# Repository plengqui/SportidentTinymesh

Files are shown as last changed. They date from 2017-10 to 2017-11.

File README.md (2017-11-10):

# Sportident online control using Tinymesh 169Mhz radio
A forest-optimized, reliable mesh radio for Sportident with up to 1,5km per hop.
This document introduces the project idea and product vision on a high level.
# Project context and background
In orienteering and other outdoor sports, the [Sportident](https://www.sportident.com/) system is often used to electronically register when a participant passes a checkpoint. One drawback of Sportident is that the checkpoint pass time registrations cannot be read out until the participant has finished the course. In order to make sports using the Sportident system more exciting for the audience, there is a need for real-time communication from the checkpoints to the competition administration at the arena. A number of solutions already exist for this, such as the excellent [Radio Online Control](http://olresultat.se/), current loop signaling over military [telephone wire](http://hem.bredband.net/sunjo/index.htm), [jSh Radio](http://radio.jsh.de/), etc. While they each have their advantages, most solutions are a bit bulky which makes it burdensome to deploy more than a couple of online checkpoints in each race. For solutions that rely on mobile data networks, there is also the risk at big competitions that the network becomes overloaded on competition day by the large number of runners and viewers appearing on the arena, which is typically a location where mobile networks are not dimensioned for such high load. 
# Product vision
This project aims to produce a neat lightweight radio solution that is easy to deploy in forest conditions, while being very reliable in terms of delivering 100% of punches to the arena in all possible weather conditions. The finished product is a radio unit - a small box about the size of a fist - which is directly attached to a flexible 130 cm roll-up antenna. The antenna + radio unit can hang from a tree anywhere within 8m from the Sportident units at the control. No cabling is needed on the ground. No calibration of directional antennas is needed.
About 10 radio units including antennas can be carried in a backpack and easily deployed by one person with very limited technical knowledge. 
# Technologies used
## Tinymesh
The radio units communicate using a widely used and well supported mesh radio protocol from Radiocrafts called Tinymesh. They use the 169 MHz band, which implies wavelengths of almost 2 meters. Thus they have very good propagation even through dense and wet forest. Distances of 1,5 km per hop have been tested with continuous operation through hilly forest with 500mW effect and Slim Jim antennas. Tinymesh is a self-configuring, self-healing, monitorable mesh technology, implemented in a small surface-mounted component containing both transceiver and protocol logic.
Nodes in a Tinymesh network can be of two types: Router or Gateway. There is only one Gateway per network. All serial data sent from Rounters are automatically routed to the Gateway.
The [Tinymesh datasheet](docs/RCxxxxHP-TM_Data_Sheet.pdf) from Radiocrafts contains everything we need to know in this project, from an overview of the solution to detailed explanation of the protocol and packet formats. I have highlighted the parts of the datasheet that are relevant to this project and added some annotations. The specific module we use is RC1701(HP)-TM, whose default operating frequency is 169.40625 MHz with max effect of 500mW.
This radio band is unlicensed in most european countries, including [Sweden](https://www.pts.se/sv/Bransch/Radio/Radiotillstand/Undantag-fran-tillstandsplikt/):
>88 § 169,400–169,475 MHz: Radiosändare för ospecificerat tillämpningsområde. Högsta effekt: 500 mW e.r.p. Kanaldelning: Upp till 50 kHz. Sändningscykel: < 1 %

>89 § 169,400–169,475 MHz: Radiosändare för mätutrustning. Högsta effekt: 500 mW e.r.p. Kanaldelning: Upp till 50 kHz. Sändningscykel: < 10 %.

## Slim Jim antenna
slimjim1 slimjim2

The Slim Jim antenna is perfect for this application, being easy to transport rolled up, and quick to deploy by just hanging it from a tree nearby, up to 8m from the Sportident station. The antenna is 130 cm long, and the small Radio Unit box can be attached diretly at the lower end of the antenna. 

## Sportident Short Range Radio (SRR)
The Sportident units at the control are [SRR](https://www.sportident.com/images/PDF/1_si_base_products/8_si-radio/SRR-Kit/SPORTident_SRR_en.pdf) stations, which communicate with the radio unit via a proprietary Sportident radio protocol on the 2,4 GHz band. 

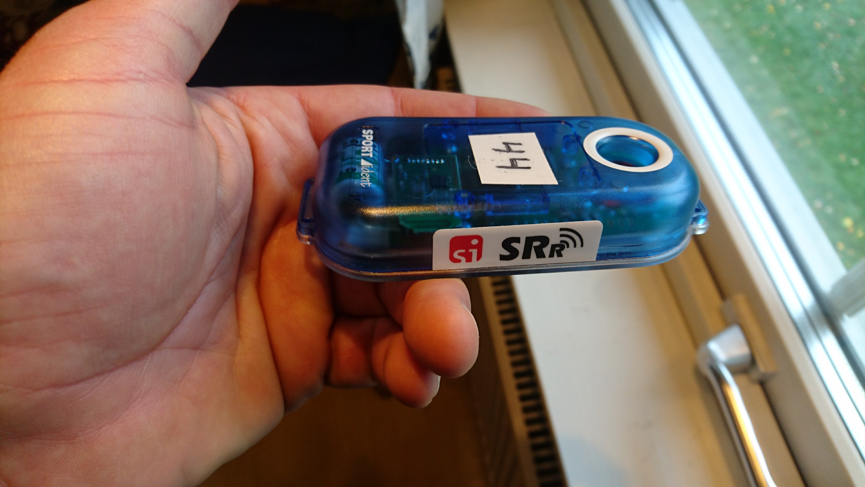
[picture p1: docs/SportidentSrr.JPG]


# System design and architecture
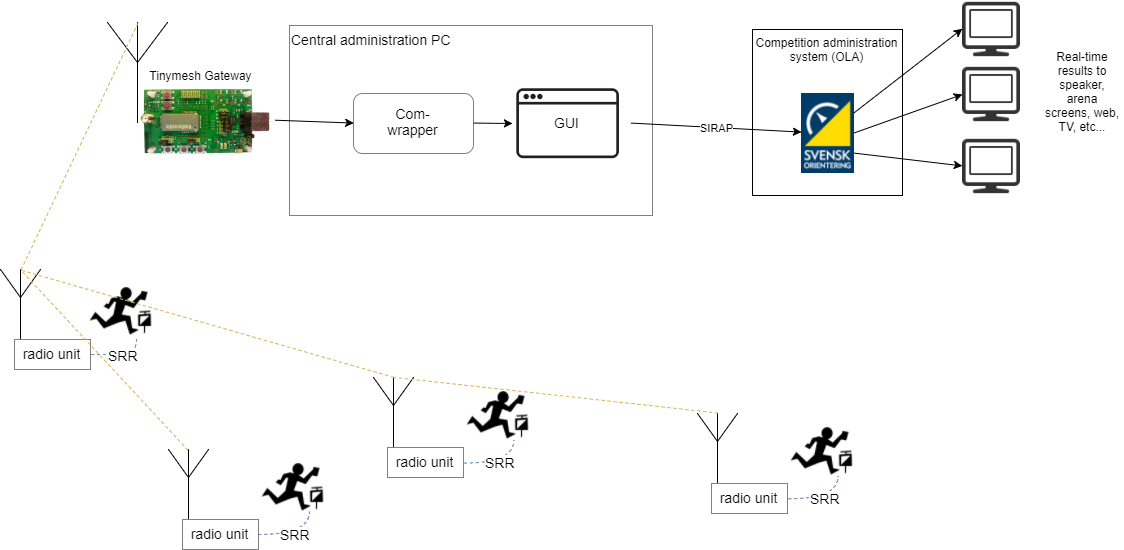
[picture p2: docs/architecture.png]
architecture

Apart from the standard off-the-shelf Sportident SRR stations, the system consists of two main parts:
1. The neat field-deployable radio unit, of which there will be one per checkpoint. The radio unit receives punch data from the Sportident stations over SRR, and retransmits it over the 169 MHz Tinymesh network. The Tinymesh network architecture has one central Gateway node to which all data is sent.
2. The Gateway, consisting of a Tinymesh radio module directly connected to a PC running our custom python Gateway Application which parses the Tinymesh packets and forwards the Sportident punch data to the competition administration system. Integrates with competition administration system like OLA or MeOS using the SIRAP protocol.
There is pretty comprehensive documentation of the Gateway Application code available in its [README](https://github.com/plengqui/GatewayApplication/blob/master/README.md).

## The radio unit

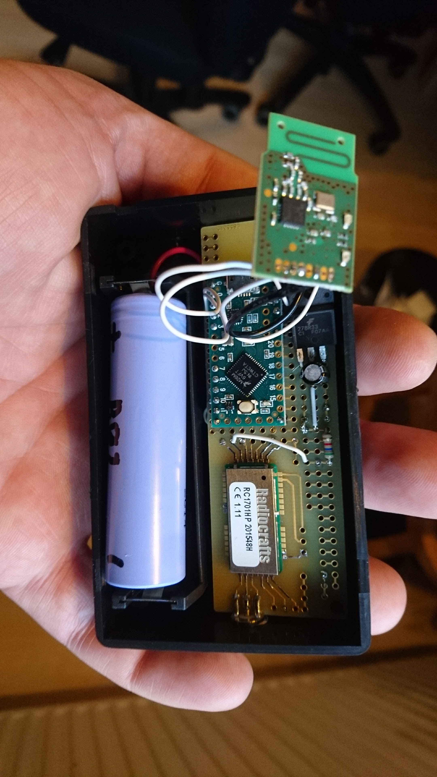
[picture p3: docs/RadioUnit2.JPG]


The radio unit is a small box of electronics with only one external connector for the SlimJim roll-up antenna. As mentioned, the antenna and the radio unit box are meant to hang from a tree nearby the checkpoint. Inside the box, there is a custom made printed
circuit board (PCB) with:
- a Sportident SRR receiver chip, which listens to 2,4GHz for punch packets and sends them out over UART serial. 
- A Teensy-LC (a cheap small Arduino style microcontroller) receives the punch data, creates a Tinymesh data packet and passes it on to the Tinymesh radio module, again over UART serial. 
- The Tinymesh radio module sends the data packet with the punch data out on the Tinymesh network which forwards it to the gateway Tinymesh module. The model number of Tinymesh used is RC1701(HP)-TM.
- The Teensy-LC microcontroller also buffers punches if the Tinymesh module should be busy or waiting for a free timeslot on the frequency. It also sends monitoring packets every 10 seconds so that the central pc application can allways know all radio units are up and connected.
- Battery: 18650 Lithium cells and a voltage regulator, serving the 3,3V needed by Tinymesh and Teensy-LC.
- Antenna for 169MHz with SMA male connector. Either a SlimJim, which you can [build](https://www.essexham.co.uk/slim-jim) or [buy](http://www.2wayelectronix.com/). Or a "normal" whip antenna like [this one](https://www.digikey.se/product-detail/en/taoglas-limited/FW.80.SMA.M/931-1195-ND/3664652). SlimJim is best for real-world application in the woods. A whip is good for lab and test.

## The Gateway
This is the central part of the system that collects all punches from all controls and forwards them to the competition administration system. It also monitors the health and connectivity status of all controls. The Gateway is a Tinymesh module configured as the gateway of the mesh network, connected with simple serial to a PC running the Gateway Application. 
To save time, I have so far used the Tinymesh Demo Kit (RC1701HP-TM-DK) which has a USB connection and appears as a logical COM port in the PC. However, it should be quite easy to use a Radio Unit as gateway (see TODOs below).

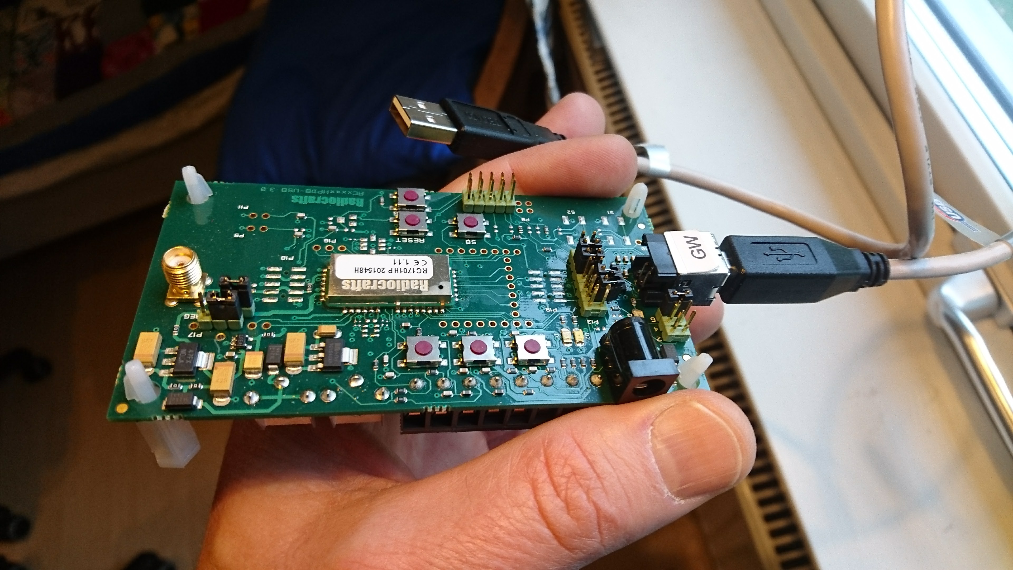
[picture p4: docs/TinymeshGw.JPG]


The Gateway Application is written in Python 3 and consists of two parts: a small simple script running as a separate process which just listens to the COM port of the Tinymesh gateway and writes every received packet to a store-and-forward queue. This queue is read by the main python application which parses each Tinymesh packet on the queue and handles it. Packets that are punch registrations are sent to the competition administration system using the SIRAP protocol. The application also has a GUI that shows status and health of each control, and any alarms:

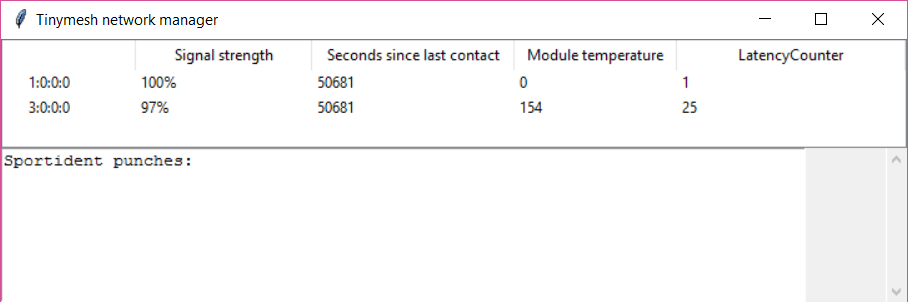
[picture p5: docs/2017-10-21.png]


The Github repository for the gateway application is [here](https://github.com/plengqui/GatewayApplication/).

# Project progress and status

This has been completed so far:
1.	Selected and tested radio, frequency and antenna solution. 1,5km hop reached with rollup slim-jim antenna using the Tinymesh RC1701(HP)-TM with 500 mW effect on the license free 169 MHz ISM band. 
2.	Verified Tinymesh mesh radio network in real Orienteering competition using Tinymesh developer kits in July 2016. Two controls and one gateway.  This worked great. All punches were received online. 
3.	Written pc application in python to receive and parse Tinymesh and Sportident packets. Use Tinymesh in packet mode, to monitor the health of the mesh network using the packet metadata and the various command packets of Tinymesh. This is referred to as the Gateway Application above. 
4.	Designed and built a neat field-deployable Radio Unit with custom made printed circuit board (PCB), surface-mounted Tinymesh chip, battery, and a Teensy (a cheap small Arduino style microcontroller) for control logic.
5.	Written and tested Teensy code to simulate Sportident punches and send them to the Tinymesh radio module. Tested connectivity from the Teensy to the python application running on the PC, over Tinymesh radio. Load tested with 3 simulated punches per second, continuously for 2 hours.
6.  Got the Sportident SRR chip working with the Radio Unit. So now full integration from Sportident punch to Gateway Application is done. Rudimentary support for flow control reading the Tinymesh CTS status before and after sending each packet. So far relies on Teensys serial buffers for buffering.
7. Implemented SIRAP protocol in the Python Gateway application. Tested with OLA competition administration system. Now we have a complete end-to-end system!

# Getting Started
List of needed components for the Radio Unit, how to get them and putting it all together is [here](./RadioUnit/README.md).

When the Radio Unit is built, you just need to:
1. connect the antenna
2. upload the sketch teensy-sportident-srr.ino to the Teensy using the [Arduino IDE](https://www.arduino.cc/en/Main/Software)
3. connect a usb power source to the micro usb of the Teensy.
4. attach the gateway demokit module to the pc.
5. start the [Gateway Application](https://github.com/plengqui/GatewayApplication/blob/master/README.md) on the PC 
6. try some punches in the SRR station!

Any problems? Just drop me an email at ```per (kanelbulle) lengquist.se```

# TODO: ideas for further improvement
-	Build more Radio Units and test in more real orienteering events. Please drop me an email if you know where to borrow more SRR master stations.
- Implement support for RS232 Sportident stations. Support in Teensy for multiple stations (multiple serial ports in).
- Select a good solution for physical enclosure. Also decide battery solution: powerbank or 18650 LiIon cells. 
- Invent a way for the person deploying the Radio Units in the forest to get verification that each deployed online control works end-to-end. Perhaps by the Gateway Application publishing its status logs on a web page or [Slack](https://api.slack.com/).
- Use a Radio Unit as Gateway instead of the rather expensive Demo Kit: Write a Teensy program to configure the Tinymesh module as a gateway. Then use a [simple Teensy program](https://github.com/arduino/Arduino/blob/master/build/shared/examples/04.Communication/MultiSerial/MultiSerial.ino) to pipe through serial data between USB serial and the Tinymesh in normal operation.

Any suggestions or feedback? Just drop me an email at ```per (kanelbulle) lengquist.se```

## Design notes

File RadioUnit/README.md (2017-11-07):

# Building the Radio Unit
Here is info about getting components and putting it together.

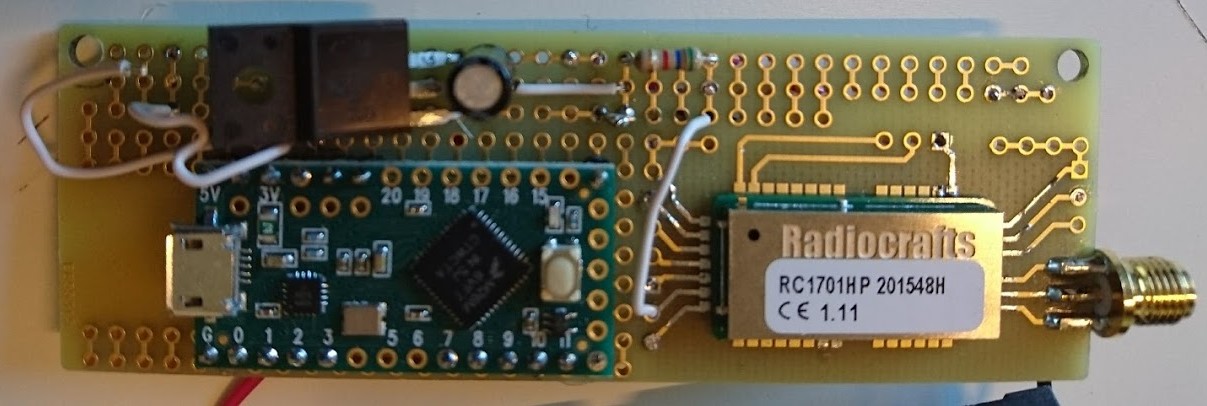
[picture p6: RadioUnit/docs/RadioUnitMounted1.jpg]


## Basic components to get a working unit up for lab/development purposes

### RC1701HP-TM	Tinymesh transciever module


Borrow a couple from me, or buy your own from:
1. http://www.actesolutions.se/sv/produkt/rcxxxx-tm (See how to order from Sweden below.)
2. https://www.digikey.com/product-detail/en/radiocrafts-as/RC1701HP-TM/RC1701HP-TM-ND/7100560 (not possible to ship to sweden)

### PCB with copper pattern for the Tinymesh module footprint
See [PCB Readme](./PCB/README.md) on how to order one.

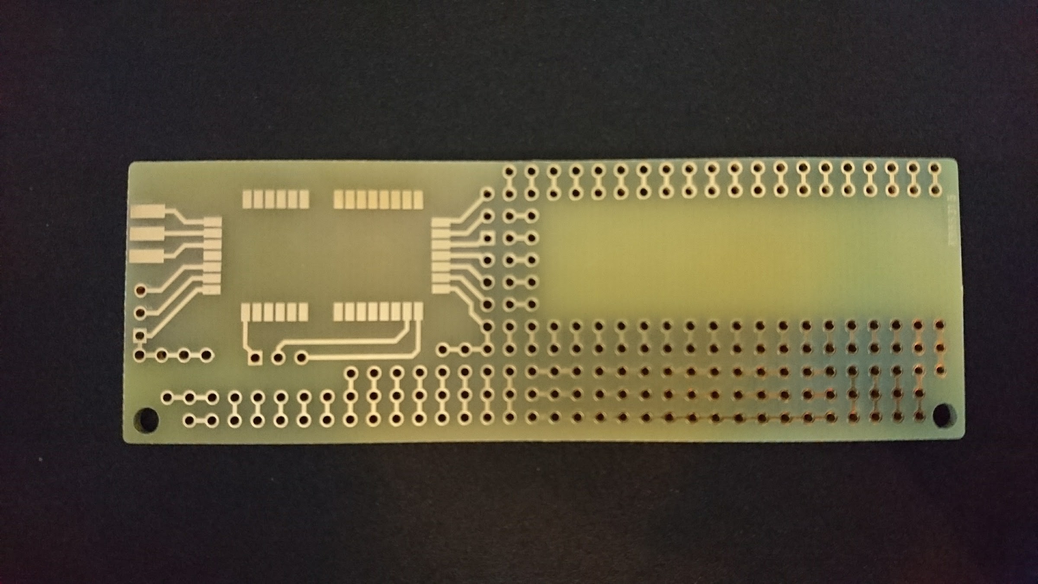
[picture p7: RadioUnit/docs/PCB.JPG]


### SMA female connector for PCB mount
https://www.electrokit.com/sma-hona-pcb-4mm-djup.49423

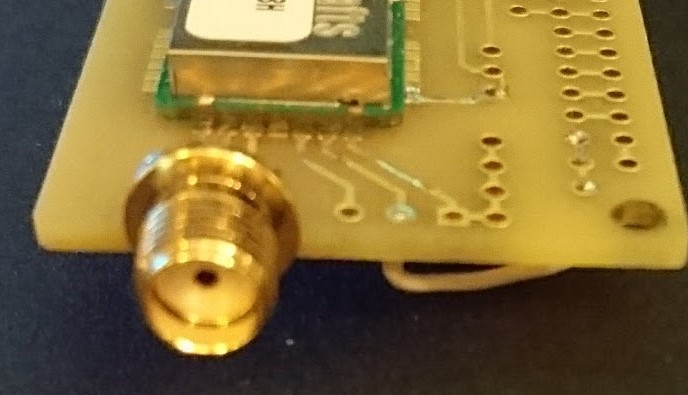
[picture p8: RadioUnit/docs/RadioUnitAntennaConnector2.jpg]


### Whip antenna for 169MHz with SMA male connector 
https://www.digikey.se/product-detail/en/taoglas-limited/FW.80.SMA.M/931-1195-ND/3664652

### Teensy-LC microcontroller
https://www.electrokit.com/teensy-lc.52909

## Connecting to a Sportident station

SRR module for connecting to SRR BSM station: 
http://www.sportident.se/order.aspx?id=472
To get the actual module (a 1x1 inch circuit board with only the SRR radio and UART connectors) you are supposed to *open up* the plastic enclosure of the dongle and *BREAK THE CIRCUIT BOARD IN HALF*! Yes, it sounds crazy but it's true. Look at the picture below and you can see the broken edge to the right. There is a notch on either side of the board where you are supposed to break it. If you want to configure if it should transmit on blue or red SRR channel, you need to do that (with SI-Config+) before you break the board.

Alternative: wired connection to RS232 BSM station
- RS232-to-UART converter
https://www.electrokit.com/en/max3232-breakout.49804
- RS323 connector
https://www.electrokit.com/en/dsub-9-conn-male.42706

## Non-mandatory extras
Teensy 3.2 may be an alternative to the Teensy-LC. The LC is cheaper, but the 3.2 has an internal voltage regulator that can feed more current (250mA) to power the Tinymesh module.
https://www.pjrc.com/teensy/external_power.html

I recommend headers for mounting the Teensy on the PCB when in the lab/design phase.
- https://www.electrokit.com/stiftlist-2-54mm-1x40p-brytbar.43412
- https://www.electrokit.com/hylslist-2-54mm-1x40p-svarvad-brytbar.44672

Some LEDs and resistors to connect to RSSI and CONN indicator outputs.

### Tinymesh Demo Kit:
https://www.digikey.com/product-detail/en/radiocrafts-as/RC1701HP-TM-DK/RC1701HP-TM-DK-ND/7100561 
I used a demo kit RC1701HP-TM-DK for the Gateway, since it is a ready made appliance that you just connect to the PC with USB. A demo kit comes with 3 units and costs about 320 USD. But you could also design and build your own gateway unit using a Teensy (which just passes serial straight through) and a Tinymesh module. 

## For maximum outdoor range
To use full transmit power, an additional voltage regulator from the USB's 5V to the Tinymesh VCC_PA that takes 3.3V. I think a buck (switched step-down) converter is better than a linear since it is more energy efficient. It is a tradeoff between battery size and complexity of design. It needs to be able to output >800mA (gut feeling estimate). Note that you may need capacitors too, check the datasheet.

Slim Jim VHF antenna tuned for 169.4MHz with SMA male connector.
http://www.2wayelectronix.com/N9TAX-Original-VHF-Slim-Jim-antenna-VHF-STD.htm

## Ordering Tinymesh in Sweden

I just sent email to Acte Solutions order@actesolutions.se .
They need you to order via a company or organization (their systems require and organization number). I used the org nr of my orienteering club whch worked fine. I just made sure I got the invoices by email so I could pay them myself.

When I ordered 2016 the prices were:
34,50 USD each for the modules RC1701HP-TM, minimum quantity 10 pcs.
320 USD each for the demokit RC1701HP-TM-DK.
Prices excluding VAD and shipping. Shipping was about 100 SEK for me. Country of origin was Norway (where Radiocrafts are).
Delivery took about 3 weeks.

## Putting it together
Connect the following:

| Tinymesh connector | Teensy pin |
| --- | --- |
| RXD | TX2 (pin 10) |
| CTS | pin 23 |
| GND | GND |
| VCC | 3.3V |

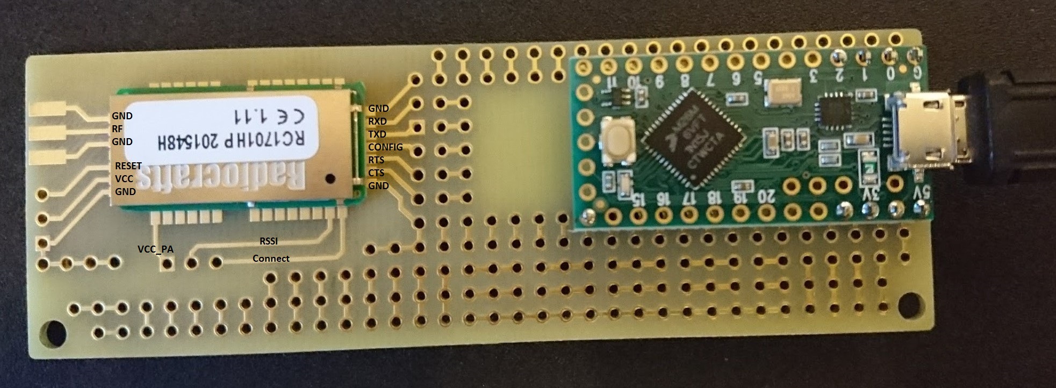
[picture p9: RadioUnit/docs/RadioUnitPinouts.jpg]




Do not connect VCC_PA of the Tinymesh to the Teensy 3.3V, since it can not supply the needed amount of current (~400mA). If you want that extra transmit power, you need to add a step-down converter from 5V to 3.3V. Take the 5V from Vin on the Teensy (which is directly connected to the power wire of the USB contact, and feed the resulting 3.3V to VCC_PA on the Tinymesh.

Solder the SMA connector to the three plates at the edge of the PCB. They are GND, RF and GND. Also solder the SMA connector to the GND plane on the back of the PCB.

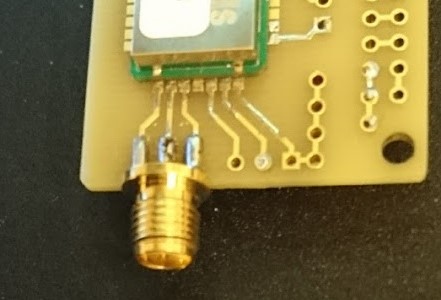
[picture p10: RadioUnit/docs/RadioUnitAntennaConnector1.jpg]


If you use the Sportident SRR module, you connect the following:

| SRR | Teensy pin |
| --- | --- |
| TX | RX1 (pin 0) |
| GND | GND |
| 3 V | 3.3V |

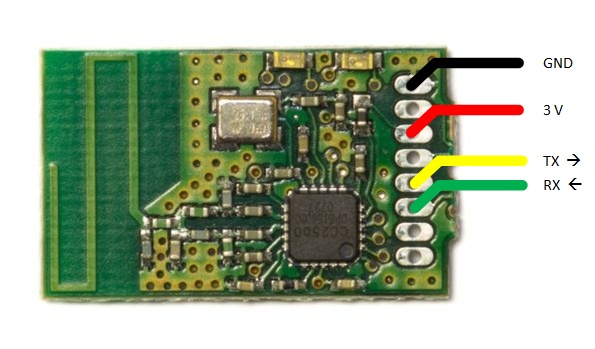
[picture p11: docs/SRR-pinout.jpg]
srr pinout


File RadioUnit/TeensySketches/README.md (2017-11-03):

# Main file
teensy-sportident-srr: The Teensy-LC scetch to use in a Radio Unit. Assumes Sportident SRR connected to RX1.

# Miscellaneous extras
crc-test:	An implementation of Sportident CRC checksum algorithm for Arduino	

punch-simulator:	Makes Teensy simulate Sportident punches and send to Tinymesh.

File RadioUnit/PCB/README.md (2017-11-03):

This directory contains design files for the Printed Circuit Board (PCB) on which the components are soldered. 
The Tinymesh module is surface-mount soldered, while the other components are traditional through-hole. 

The board design has no fixed copper wiring between the components. This makes it possible to use for experimentation and test different designs without printing new PCBs.

The files are created using [Eagle](https://www.autodesk.com/products/eagle/free-download).
I ordered the boards from [Eurocircuits](https://www.eurocircuits.com/blog/NAKED-proto/). 
5 boards cost 48,5 EUR incl VAT and shipping. See order details in the file [E855315.pdf](./E855315.pdf). If you refer to that, or maybe "PCB B0826634", and they have saved my specification and design, you may be able to order new copies the exact same PCB that I got. I can confirm it is suitable for the components I used including the Tinymesh module. 

Here is a good video tutorial (from the great Collin's Lab) on hand solering a surface mount component with QFN package like the Tinymesh module:
https://youtu.be/QzoPxvIM2qE?t=349

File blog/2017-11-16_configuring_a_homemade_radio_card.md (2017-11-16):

# How to configure your radio card with TM-CCT
If you have built a new radio card with a TM and a Teensy, you probably want to configure the TM. At least you need to do that with your gateway since all TM's are factory configured as a router.

Radiocrafts has a real useful and easy to use tool that can be used for configuring the TM. It can also be used for sending test strings between TM's and watching the signal levels. The name of the tool is TM-CCT and it can be downloaded from [here](https://radiocrafts.com/products/tinymesh/#software). Pick the file "[RC Tools - TM](https://radiocrafts.com/uploads/rctools-tm_setup_1_06.exe)" and install it.

For TM-CCT to be able to talk to the TM through the Teensy you need a small sketch that copies everything from the USB-serial to the TM-serial and vice versa. Upload the sketch [tm-config.ino](https://github.com/plengqui/SportidentTinymesh/tree/master/RadioUnit/TeensySketches/tm-config) to the Teensy.

When the sketch is running on the Teensy, start the TM-CCT tool and connect it to the Teensy USB-serial port. Use the default 19200 as baud rate.

Now you are in normal mode (not configuration mode) and when you type something and press enter, it is sent to the TM and you should see the LEDs blinking as the TM transmits what you typed.

To enter configuration mode, click the green and red button on the top left. A dialog saying "Waiting for prompt sign, press CONFIG button!" is shown. While this dialog is showing, shortly connect the CONFIG pin on the TM to GND. (Best is probably to install a push button on the PCB in the final design but for now a jumper wire will do just fine.)

If you suceeded to set the TM in configuration mode both the LEDs should be lit with a steady light and the dialog in TM-CCT should have closed. You can now remove the jumper cable again.

Fetch the current configuration of the TM by clicking the green left arrow. The window to the left should fill up with all current configuration.

Change whatever value that you like, e.g. the Device type on address 0x0E. When finished, click the green right arrow to write the new configuration to the TM.

Go back to the normal terminal mode again by clicking the other button saying "abc123" (or type "X" and Enter). This should turn off the LEDs so they start to blink again and the TM is restarted with the the new config.

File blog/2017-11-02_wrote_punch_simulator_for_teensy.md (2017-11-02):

# Wrote a punch generator for tests
Today I wrote a Teensy program (sketch) to generate synthetic Sportident punches for test purposes.
It went well. The sketch is checked in to [the github repository](https://github.com/plengqui/SportidentTinymesh/tree/master/RadioUnit/TeensySketches/punch-simulator).
The trickiest part was writing the CRC calculating function. I only found a java implementation, which i transcribed to C. 
Each iteration the sketch increments: SI card number by one, punch time by 256 seconds, and memory pointer by 8.
I let it churn out 2-3 punches per second and actually found a timing error in the comwrapper.py script which I fixed. After that it chugged along happily for hours :-)

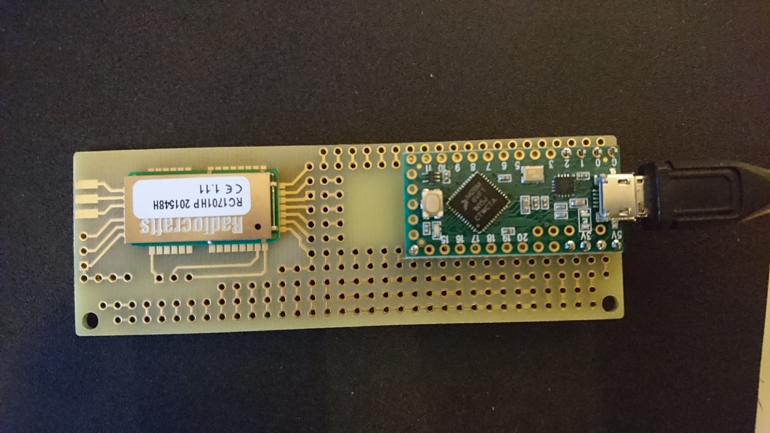
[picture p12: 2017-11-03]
RadioUnit/docs/RadioUnit1.JPG

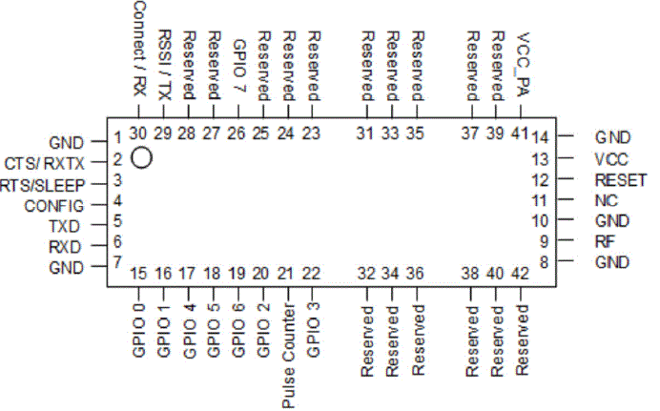
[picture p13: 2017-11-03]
docs/TM.GIF

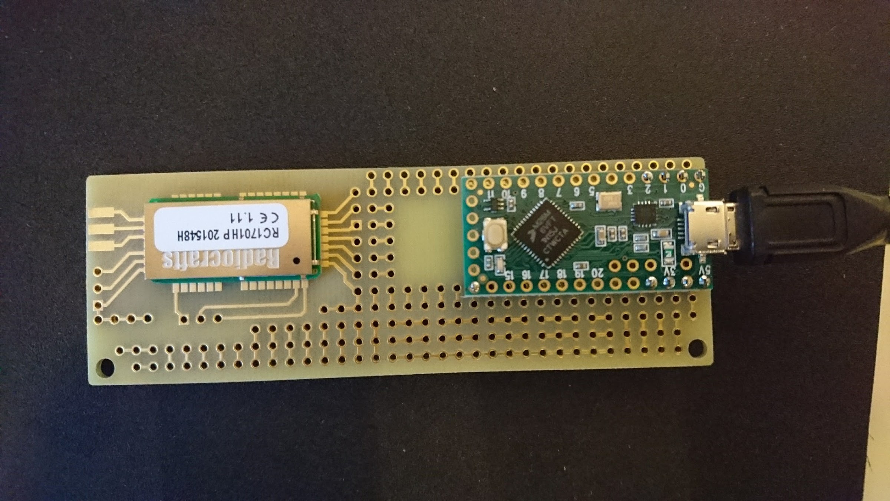
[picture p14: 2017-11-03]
RadioUnit/docs/RadioUnit2.JPG

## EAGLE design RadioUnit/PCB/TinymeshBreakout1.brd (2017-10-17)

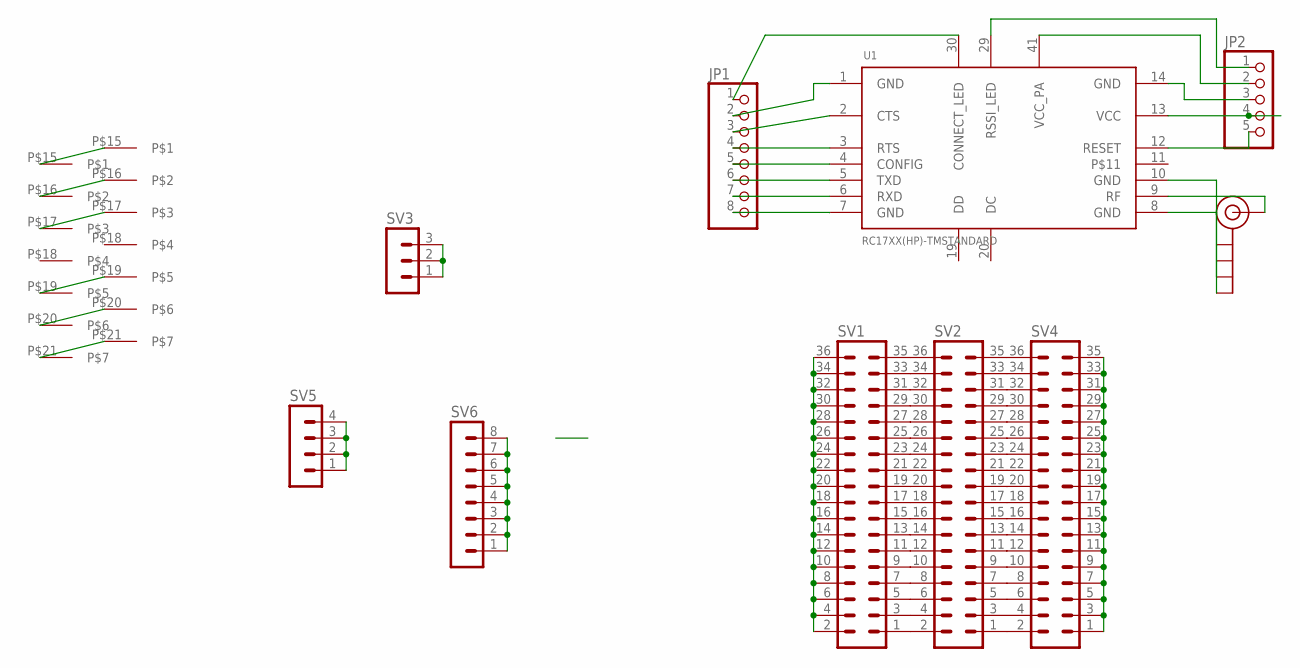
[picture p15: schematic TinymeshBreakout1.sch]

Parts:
J$1: SMA_EDGE; SMA-EDGE
JP1: PINHD-1X8; 1X08
JP2: PINHD-1X5; 1X05
SV1, SV2, SV4: MA18-2
SV3: MA03-1
SV5: MA04-1
SV6: MA08-1
U1: RC17XX(HP)-TMSTANDARD; RC17XX(HP)-TM
U$1, U$2: OEMSRR

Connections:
GND: J$1.GND@2 (GND), J$1.GND@3 (GND), JP1.2, JP2.3, SV1.2, SV1.4, SV1.6, SV1.8, SV1.10, SV1.12, SV1.14, SV1.16, SV1.18, SV1.20, SV1.22, SV1.24, SV1.26, SV1.28, SV1.30, SV1.32, SV1.34, SV1.36, U1.1 (GND), U1.8 (GND), U1.10 (GND), U1.14 (GND)
unnamed: SV1.1, SV2.2
unnamed: SV1.3, SV2.4
unnamed: J$1.SIG (SIGNAL), U1.9 (RF)
unnamed: JP2.5, U1.12 (RESET)
unnamed: SV1.5, SV2.6
unnamed: SV1.7, SV2.8
unnamed: SV1.9, SV2.10
unnamed: SV1.11, SV2.12
unnamed: JP1.7, U1.6 (RXD)
unnamed: JP1.6, U1.5 (TXD)
unnamed: JP1.5, U1.4 (CONFIG)
unnamed: JP1.4, U1.3 (RTS)
unnamed: JP1.3, U1.2 (CTS)
unnamed: SV1.13, SV2.14
unnamed: JP1.1, U1.30 (CONNECT_LED)
unnamed: JP2.1, U1.29 (RSSI_LED)
unnamed: SV1.15, SV2.16
unnamed: SV1.17, SV2.18
unnamed: SV1.19, SV2.20
unnamed: SV1.21, SV2.22
unnamed: SV1.23, SV2.24
unnamed: SV1.25, SV2.26
unnamed: SV1.27, SV2.28
unnamed: SV1.29, SV2.30
unnamed: SV1.31, SV2.32
unnamed: SV1.33, SV2.34
unnamed: SV1.35, SV2.36
unnamed: SV2.1, SV4.2
unnamed: SV2.3, SV4.4
unnamed: SV2.5, SV4.6
unnamed: SV2.7, SV4.8
unnamed: U$1.P$15, U$2.P$15
unnamed: JP2.4, U1.13 (VCC)
unnamed: JP1.8, U1.7 (GND)
unnamed: SV2.9, SV4.10
unnamed: SV2.11, SV4.12
unnamed: SV2.13, SV4.14
unnamed: SV2.15, SV4.16
unnamed: SV2.17, SV4.18
unnamed: SV2.19, SV4.20
unnamed: SV2.21, SV4.22
unnamed: SV2.23, SV4.24
unnamed: SV2.25, SV4.26
unnamed: SV2.27, SV4.28
unnamed: SV2.29, SV4.30
unnamed: SV2.31, SV4.32
unnamed: SV2.33, SV4.34
unnamed: SV2.35, SV4.36
unnamed: U$1.P$16, U$2.P$16
unnamed: SV4.1, SV4.3, SV4.5, SV4.7, SV4.9, SV4.11, SV4.13, SV4.15, SV4.17, SV4.19, SV4.21, SV4.23, SV4.25, SV4.27, SV4.29, SV4.31, SV4.33, SV4.35
unnamed: U$1.P$17, U$2.P$17
unnamed: U$1.P$19, U$2.P$19
unnamed: U$1.P$20, U$2.P$20
unnamed: U$1.P$21, U$2.P$21
unnamed: SV5.1, SV5.2, SV5.3, SV5.4
unnamed: SV6.1, SV6.2, SV6.3, SV6.4, SV6.5, SV6.6, SV6.7, SV6.8
unnamed: SV3.1, SV3.2, SV3.3
VCC: JP2.2, U1.41 (VCC_PA)

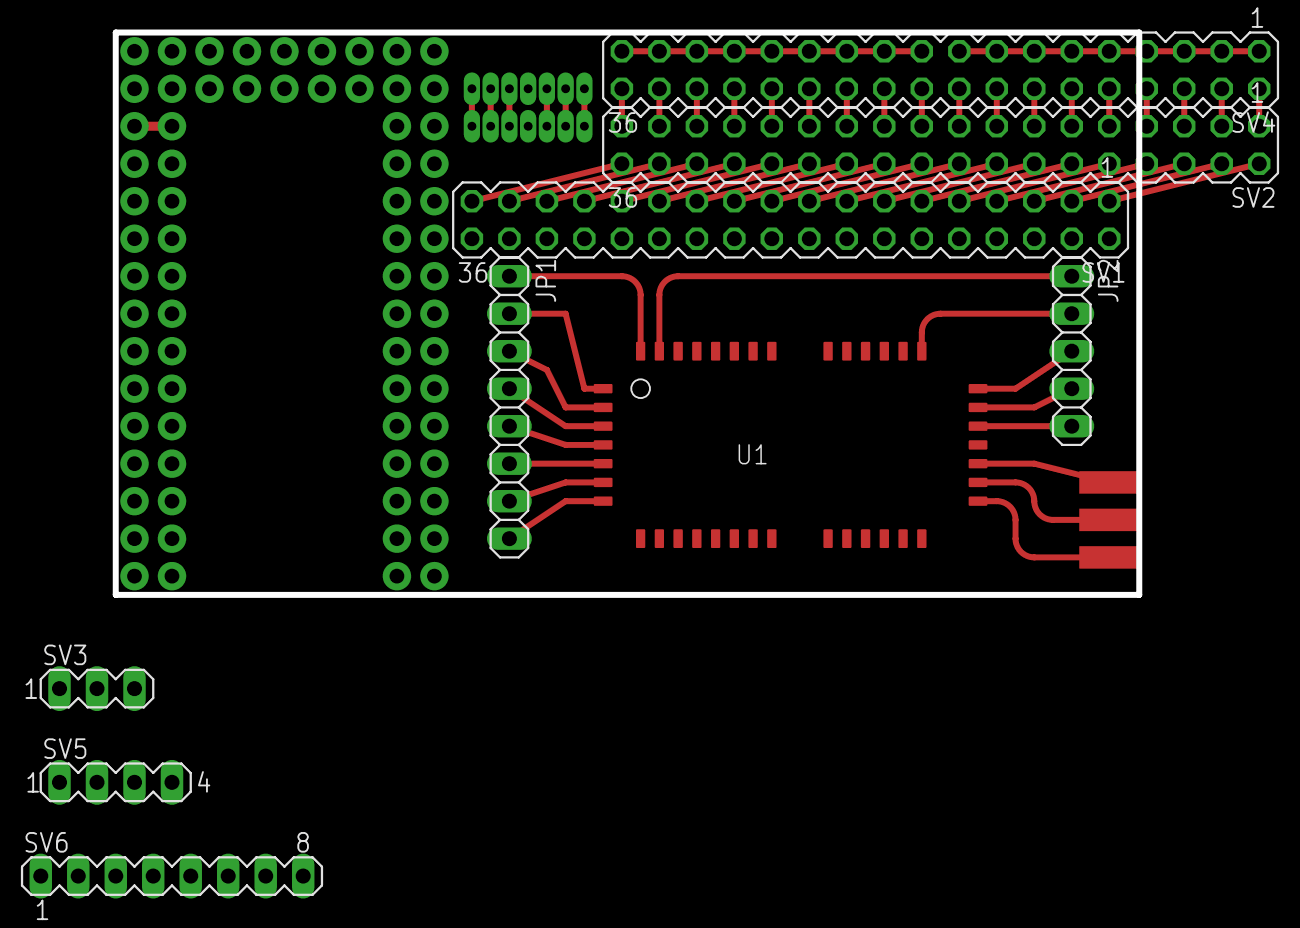
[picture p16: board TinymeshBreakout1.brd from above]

Board: 2 copper layers, 12 parts (0 on the bottom side), 59 nets.

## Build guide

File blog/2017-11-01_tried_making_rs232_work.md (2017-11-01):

# Failed attempt at making RS232 work in place of SRR
Tried to use my [MAX3232 RS232 Serial Port To TTL Converter Module Male DB9 COM ME](https://www.ebay.com/itm/RS232-Serial-Port-To-TTL-Converter-Module-MAX3232-DB9-Connector-With-Cable-MO-/152193124831) as serial input to the teensy instead of the SRR module. Did not work. Teensy reads only gibberish on the serial input, regardless of whether a punch is made or not. 

Setup:
RS232 Sportident station connected to my "MAX3232 RS232 Serial Port To TTL Converter Module Male DB9 COM ME". 
Connected the converter module TXD pin to pin 0 (UART RX1) of the Teensy. It only read random gibberrish, at bursts. 
I used 4800 baud on both the Sportident station and the Teensy serial port.

To analyze what was actually sent, I wrote a small "logic analyzer" to run on the Teensy. See code below.
On my Teensy, each measurement lasted 11 ms with a resolution of 0.011 ms, which should be ok since on bit at 4800 baud is 0.21 ms. 
I pasted the serial monitor output into an excel sheet and drew a diagram of it. The captured measurement showed random noise between 0.2 and 0.9V, which is what I got with no input attached at all.
I tried to connect to the RXD pin of the converter module instead (just to check) and it read 3,3V constantly. I also tried modifying the logic analyzer script to trigger on low bit (less than 800 analogread), with the same results, i.e. it never triggered when punching.
Bottom line: i could not get anything that resembled real UART TTL bits out of my converter module. So I will throw those in the bin. Bought them on ebay...

## Links
- [RS232 and UART overview](https://www.sparkfun.com/tutorials/215)
- [Max3232 datasheet](http://www.ti.com/lit/ds/symlink/max3232.pdf)
- [Teensy serial UART overview](https://www.pjrc.com/teensy/td_uart.html)
- [Using timers with elapsedMillis](https://www.pjrc.com/teensy/td_timing_elaspedMillis.html)

## Logic analyzer output (as Excel diagrams)
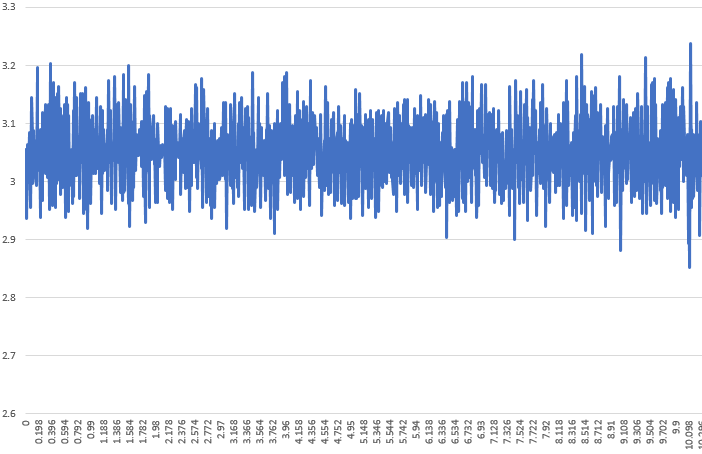
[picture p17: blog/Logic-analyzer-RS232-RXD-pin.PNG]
RXD pin:  

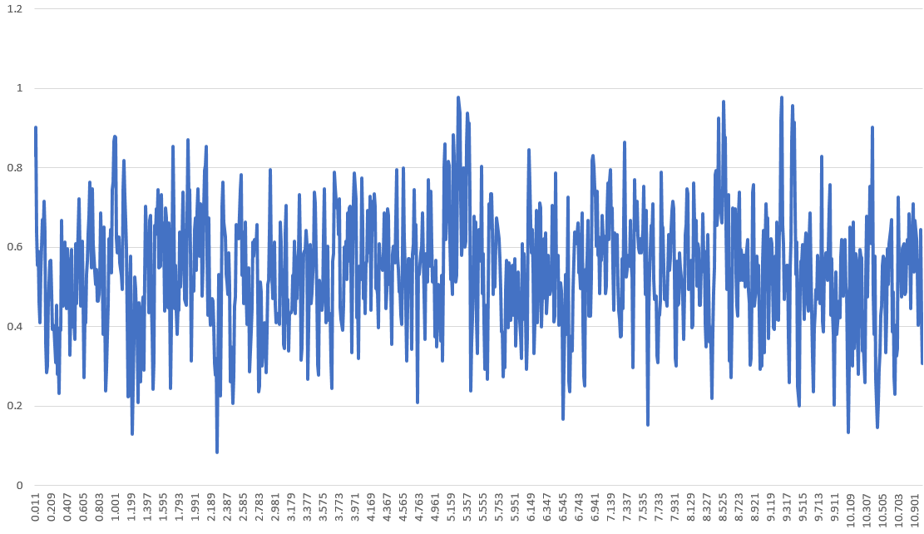
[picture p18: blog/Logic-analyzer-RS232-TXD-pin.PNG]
TXD pin: 

As it should be, a punch from SRR module: 
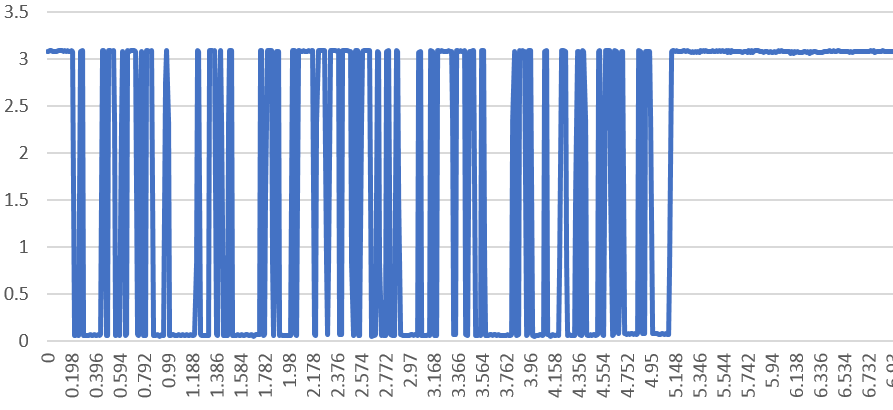
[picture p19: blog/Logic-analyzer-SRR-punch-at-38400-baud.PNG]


## Logic analyzer sourcecode
Logicanalyzer.ino
```
int led = 13;
int a = 0; //which analog port
int x = 1000; //the analog measured value
const int n = 1000; //number of samples in each measurement
int xs[n]; //array to put the measurements in
elapsedMillis t=0;
void setup() {
  // put your setup code here, to run once:
  Serial.begin(9600);
  pinMode(led, OUTPUT);
  digitalWrite(led,HIGH);
  delay(10000); //Time to start the serial monitor.
  digitalWrite(led,LOW);
  Serial.println("Ready!");     
}

void loop() {
  Serial.println("Waiting for first high bit...");     
  while(analogRead(a) < 500){ //Wait for first high bit on serial
  }
  Serial.println("Reading!");     
  digitalWrite(led,HIGH);
  t=0;
  for(int i=0;i<n;i++){
    xs[i] = analogRead(a);
  }
  Serial.println("Done reading!");     
  Serial.print("Time ");
  Serial.println(t);
  digitalWrite(led,LOW);     
  delay(2000);
  for(int i=0;i<n;i++){
    Serial.println(xs[i]); 
  }
  delay(10000);

}
```

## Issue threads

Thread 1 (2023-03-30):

Kit for radio controls

geotibi, 2023-03-30:
Will it work if I buy a kit https://www.digikey.com/product-detail/en/radiocrafts-as/RC1701HP-TM-DK/RC1701HP-TM-DK-ND/7100561 and use one as gateway (plug and play) and the others 2 can I modify to connect SRR dongle or open a SRR dongle and solder the pins to one board from the development kit? I want to avoid building it from scratch. Also one additional question: will software from http://radio.jsh.de/ running?

geotibi, 2023-03-30:
Or maybe to use USB Type A Female to USB Type B Male Adapter ?

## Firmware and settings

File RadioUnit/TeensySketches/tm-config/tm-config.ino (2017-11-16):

#include "Arduino.h"

const int ledPin = 13;      // The number of the LED pin
const int ctsPin = 14;		// Clear to send from TM

#define usbSerial Serial	// USB cable to PC (and TM-CCT)
#define tmSerial Serial2	// Serial TX/RX connected to TM

// The setup function is called once at startup of the sketch
void setup() {
    pinMode(ledPin, OUTPUT);
    pinMode(ctsPin, INPUT);

    usbSerial.begin(19200);
    tmSerial.begin(19200);

    usbSerial.println("Waiting for TM-CCT to connect");
}

// The loop function is called in an endless loop
void loop() {
    // If a character is available from the USB and TM is ready to receive, copy the char to TM
    if (usbSerial.available() && digitalRead(ctsPin) == LOW) {
        tmSerial.write(usbSerial.read());
    }

    // If TM has returned a character, copy it to the USB port
    if (tmSerial.available()) {
        usbSerial.write(tmSerial.read());
    }
}

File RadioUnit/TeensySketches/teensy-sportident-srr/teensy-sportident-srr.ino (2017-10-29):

/* Check for incoming Sportident punch packets on Serial1 from a Sportident SRR-OEM module.
 * Forward the punches on Serial2 to a Tinymesh radio module.
 * The sending waits if the CTS line is HIGH (should be connected to pin 23).
 * 
 */




//A normal sportident punch is 20 bytes. Example:
//255, 2, 211, 13, 0, 44, 0, 3, 171, 90, 37, 102, 247, 13, 0, 1, 192, 251, 107, 3
int led = 13;
int sw_cts = 23;

void setup() {
  Serial.begin(9600);
  Serial1.begin(38400);
  //Serial1.setTimeout(500); //50 milliseconds
  //38400 baud means 3840 char/sec means 5 ms to send 20 characters
  //4800 baud means 480 char/sec means 42 ms to send 20 characters
  Serial2.begin(19200);
  pinMode(sw_cts, INPUT);
  pinMode(led, OUTPUT);
  digitalWrite(led,HIGH);
  delay(2000);
  
  Serial.println("Serial: Control booted");
  Serial2.println("Serial2: Control booted");
  digitalWrite(led,LOW);     
}

int maxSize=20; //normal sportident punch autosend packets are 20 bytes (in extended protocol mode)
int len=0;
int waitingBytes=0;
boolean sent=true;
char inData[20]; // Allocate some space for the string

void loop()
{
  waitingBytes=Serial1.available();
  Serial.println(waitingBytes);
  while(waitingBytes > 0) 
  {
    digitalWrite(led,digitalRead(sw_cts));     
    len=Serial1.readBytes(inData,maxSize);
    Serial.print("New packet len=");
    Serial.println(len);
    sent=false;
    while(!sent){  //todo: use a buffer of packets, not only one single packet
      sent=trySend(inData,len);
    }
    waitingBytes=Serial1.available();
  }
  Serial.print("z");
  delay(1000);
}

boolean trySend(char data[], int len) {  //return true if packet was sent and CTS did not go high during transmission
  digitalWrite(led,digitalRead(sw_cts));     
  if(digitalRead(sw_cts)==HIGH){
    //CTS is high = we are not allowed to send
    digitalWrite(led,HIGH);
    return(false);
  } else {
    //CTS is low = now we can send a packet
    for (int i=0; i<len; i++) {
      Serial.print(data[i],DEC); 
      Serial.print(','); 
      Serial2.print(data[i]); //TODO: put into a buffer and send it with cts support
    }
    Serial.println(".");
  }
  digitalWrite(led,digitalRead(sw_cts));     
  return(digitalRead(sw_cts)==LOW); //Only return success if CTS was low before and after transmission
}

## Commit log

2017-10-17 Added PCB, Teensy Scetches, and some photos.
    [TinymeshBreakout1.brd, TinymeshBreakout1.sch]
2017-10-27 Photo that shows pinout of a SRR-OEM board.
2017-10-29 teensy scetch
2017-11-01 Sportident CRC for Arduino
2017-11-01 Makes Teensy simulate Sportident punches and send to Tinymesh
2017-11-02 Bill of materials

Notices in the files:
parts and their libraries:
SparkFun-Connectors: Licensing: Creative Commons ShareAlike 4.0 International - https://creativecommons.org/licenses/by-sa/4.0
